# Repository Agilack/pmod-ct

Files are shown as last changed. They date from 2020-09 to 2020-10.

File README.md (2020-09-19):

PMOD Current Transformer
========================

This PMOD allow to interface a current transformer (CT) for current measurement
with no direct electrical coupling. This PMOD use a type 2 (SPI) port to
control the embedded 12 bits analog to digital converter.

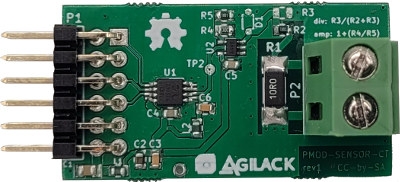
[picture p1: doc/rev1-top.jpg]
Picture of PMOD-CT rev1


CAD source
----------

This board has been designed using KiCad EDA (version 5). All sources files
(schematics, routing, ...) are available into the `prj-kicad` folder. You can
re-use this design under terms of the Creative Commons ShareAlike license
(CC BY-SA)

<table>
<tr>
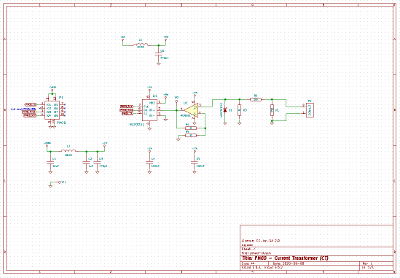
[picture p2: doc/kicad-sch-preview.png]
KiCad Schematics
<td></td>
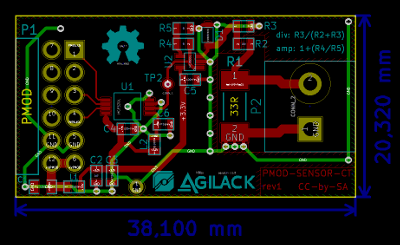
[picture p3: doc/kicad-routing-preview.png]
KiCad routing
<td></td>
</tr>
<tr>
<td>Fig1: Preview of the KiCad schematics</td>
<td>Fig2: Preview of the KiCad routing</td>
</tr>
</table>

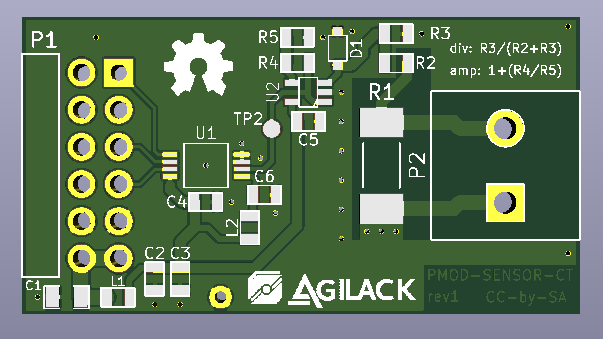
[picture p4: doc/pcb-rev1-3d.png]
PCB 3D Preview


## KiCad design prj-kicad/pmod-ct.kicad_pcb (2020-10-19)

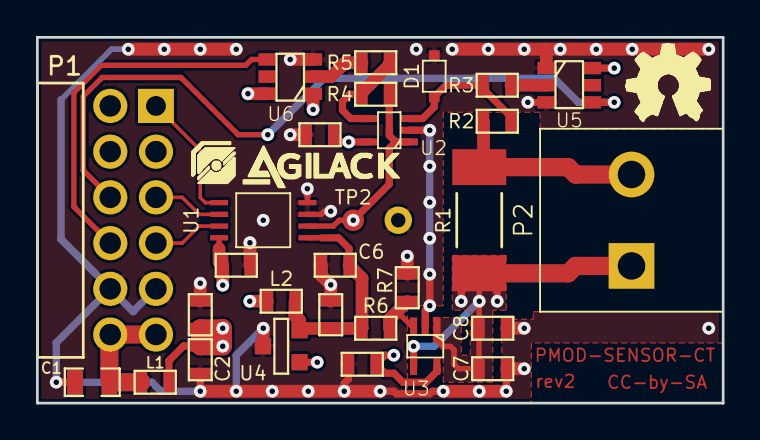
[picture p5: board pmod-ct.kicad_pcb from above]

Board: 4 copper layers, 38.1 x 20.3 mm, 32 parts (0 on the bottom side), 17 nets.

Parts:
C1: 10uF; SMD0805
C2: 1uF; SMD0603
C3, C6, C8: 470pF; SMD0603
C4, C5, C9, C10: 100nF; SMD0603
C7: 4,7uF; SMD0603
D1: MM3Z3V3T1G; SOD323
L1, L2: FB100; SMD0603
P1: PMOD; CONN_PMOD-Male
P2: CONN_2; CONN_MC000034
R1: 33R; SMD2010
R2, R6, R7: 10k; SMD0603
R3, R4, R5: R; SMD0603
TP1: CONN_1; TP
TP2: CONN_1; TP_SMD
U1: MCP3201; MSOP-8
U2, U3: MCP6001; SC70-5
U4: REF30xx; SOT23-3
U5, U6: ADG802; SOT23-6
agilack-11.5: 450px; logo-agilack-11.5
ohw_logo: VAL**; logo-ohw

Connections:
+3.3V: C2.1, C3.1, C4.1, C5.1, C9.1, L1.2, L2.1, U1.8, U2.5, U3.5, U4.1, U5.6, U6.6
+VPMOD: C1.1, L1.1, P1.6, P1.12
+VRef: C6.1, C10.1, L2.2, R6.2, U1.1, U4.2
/VREF\2: C7.1, C8.1, P2.1, R1.2, U3.1, U3.4, U6.1
AMP: P1.10, U6.4
DIV: P1.9, U5.4
GND: C1.2, C2.2, C3.2, C4.2, C5.2, C6.2, C7.2, C8.2, C9.2, C10.2, D1.1, P1.5, P1.11, R7.1, TP1.1, U1.3, U1.4, U2.2, U3.2, U4.3, U5.1, U5.3, U6.3
unnamed: D1.2, R2.1, R3.1, U2.3
unnamed: P2.2, R1.1, R2.2
unnamed: R3.2, U5.2
unnamed: R4.1, R5.2, U2.4
unnamed: R4.2, TP2.1, U1.2, U2.1
unnamed: R5.1, U6.2
unnamed: R6.1, R7.2, U3.3
PMOD_CS: P1.1, U1.5
PMOD_MISO: P1.3, U1.6
PMOD_SCK: P1.4, U1.7

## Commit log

2020-09-08 --=={ Initial version }==-- ADD schematics and routing
    [pmod-ct.kicad_pcb, pmod-ct.sch]
2020-09-10 = ADD: Create production files
    [pmod-ct-B.Cu.gbr, pmod-ct-B.Mask.gbr, pmod-ct-B.Paste.gbr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]
2020-09-19 = ADD: Insert picture of the board rev1
2020-10-17 Start rev2 design - Add voltage offset (VREF/2) for the burden resistor
    [pmod-ct.kicad_pcb, pmod-ct.sch]
2020-10-18 Rev2: PCB is now 4 layers ; add a switch to control input divider
    [pmod-ct.kicad_pcb, pmod-ct.sch]
2020-10-19 Rev2: Add a switch to control amplifier gain (G=1 or G=~10)
    [pmod-ct.kicad_pcb, pmod-ct.sch]

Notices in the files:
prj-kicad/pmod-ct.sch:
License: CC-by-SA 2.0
